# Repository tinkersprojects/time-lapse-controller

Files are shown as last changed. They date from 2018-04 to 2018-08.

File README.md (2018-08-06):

# programable Time Lapse Controller
[https://tinkersprojects.com/](https://tinkersprojects.com/)

This is a programable time lapse for a Go-Pro where tiles on the track deterands how it moves. The system can move in backward/forwards, rotate the camera and soon tilt the camera (when i get more time). It uses Lego train track as the track to guide it along and place programing tiles. The tiles are different colors which get a colour sensor reads and changes moving mode.

Currently there are 4 colours with 4 different modes. Green (also starting mode) is full travel speed with no other movements. Blue is start rotation of camera. Yellow is half the speed. Red is stop. More colours will be added soon.
The wheels are held in place with 2 x 20mmxM3 screws and driven by a 28byj-48 stepper motor. The system can be run from a 9V battery but cannot last long with out being replaced.

The PCB can be purchased from https://tinkersprojects.com/product/time-lapse-controller/

## Keep up to date
New Parts will be added, Keep up to date by following:
- Project page -> http://tinkersprojects.com/project/programable-time-lapse/
- This Thing -> https://www.thingiverse.com/thing:2825424
- my Profile -> https://www.thingiverse.com/haybailes/about

## See Other Projects
Have a look at this and other projects that I have done: http://tinkersprojects.com/

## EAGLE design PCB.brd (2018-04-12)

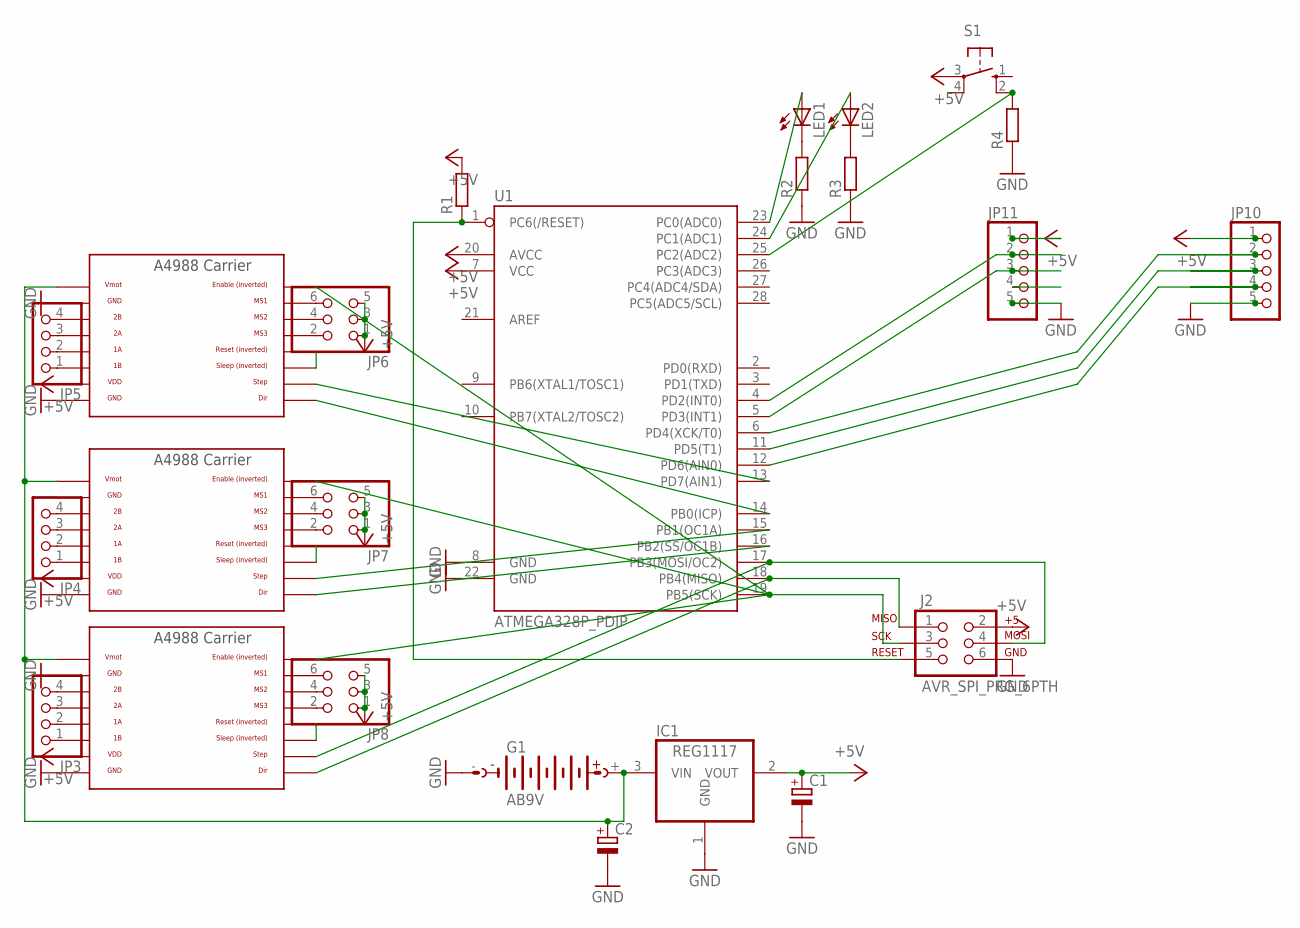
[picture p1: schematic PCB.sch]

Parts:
C1, C2: CPOL-EUE3.5-8; E3,5-8
G1: AB9V
IC1: REG1117; SOT223
J2: AVR_SPI_PRG_6PTH; 2X3
JP3, JP4, JP5: PINHD-1X4; 1X04
JP6, JP7, JP8: PINHD-2X3; 2X03
JP10, JP11: PINHD-1X5; 1X05
LED1, LED2: LED5MM
R1, R2, R3, R4: R-EU_0207/10; 0207/10
S1: 10-XX; B3F-10XX
U1: ATMEGA328P_PDIP; DIL28-3
U$1, U$2, U$4: A4988BREAKOUT

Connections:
+5V: C1.+, IC1.2 (VOUT), J2.2, JP6.1, JP6.3, JP6.5, JP7.1, JP7.3, JP7.5, JP8.1, JP8.3, JP8.5, JP10.1, JP11.1, R1.2, S1.3, U1.7 (VCC), U1.20 (AVCC), U$1.VDD, U$2.VDD, U$4.VDD
GND: C1.-, C2.-, G1.-, IC1.1 (GND), J2.6, JP10.5, JP11.5, R2.1, R3.1, R4.1, U1.8 (GND), U1.22 (GND), U$1.GND, U$1.GND@0 (GND), U$2.GND, U$2.GND@0 (GND), U$4.GND, U$4.GND@0 (GND)
unnamed: U$1.RST, U$1.SLP (SLEEP)
unnamed: U$2.RST, U$2.SLP (SLEEP)
unnamed: C2.+, G1.+, IC1.3 (VIN), U$1.VMOT, U$2.VMOT, U$4.VMOT
unnamed: J2.1, U1.18 (PB4(MISO)), U$2.DIR
unnamed: J2.3, U1.19 (PB5(SCK)), U$1.EN, U$2.EN, U$4.EN
unnamed: J2.4, U1.17 (PB3(MOSI/OC2)), U$2.STEP
unnamed: J2.5, R1.1, U1.1 (PC6(/RESET))
unnamed: JP3.1, U$2.1B
unnamed: JP3.2, U$2.1A
unnamed: JP3.3, U$2.2A
unnamed: JP3.4, U$2.2B
unnamed: JP4.1, U$1.1B
unnamed: JP4.2, U$1.1A
unnamed: JP4.3, U$1.2A
unnamed: JP4.4, U$1.2B
unnamed: JP5.1, U$4.1B
unnamed: JP5.2, U$4.1A
unnamed: JP5.3, U$4.2A
unnamed: JP5.4, U$4.2B
unnamed: JP6.2, U$4.MS3
unnamed: JP6.4, U$4.MS2
unnamed: JP6.6, U$4.MS1
unnamed: JP7.2, U$1.MS3
unnamed: JP7.4, U$1.MS2
unnamed: JP7.6, U$1.MS1
unnamed: JP8.2, U$2.MS3
unnamed: JP8.4, U$2.MS2
unnamed: JP8.6, U$2.MS1
unnamed: JP11.2, U1.4 (PD2(INT0))
unnamed: JP11.3, U1.5 (PD3(INT1))
unnamed: JP10.2, U1.6 (PD4(XCK/T0))
unnamed: JP10.3, U1.11 (PD5(T1))
unnamed: JP10.4, U1.12 (PD6(AIN0))
unnamed: U1.13 (PD7(AIN1)), U$4.STEP
unnamed: U1.14 (PB0(ICP)), U$4.DIR
unnamed: U$4.RST, U$4.SLP (SLEEP)
unnamed: U1.15 (PB1(OC1A)), U$1.STEP
unnamed: U1.16 (PB2(SS/OC1B)), U$1.DIR
unnamed: LED1.A, U1.23 (PC0(ADC0))
unnamed: LED2.A, U1.24 (PC1(ADC1))
unnamed: LED1.K (C), R2.2
unnamed: LED2.K (C), R3.2
unnamed: R4.2, S1.2 (S1), U1.25 (PC2(ADC2))

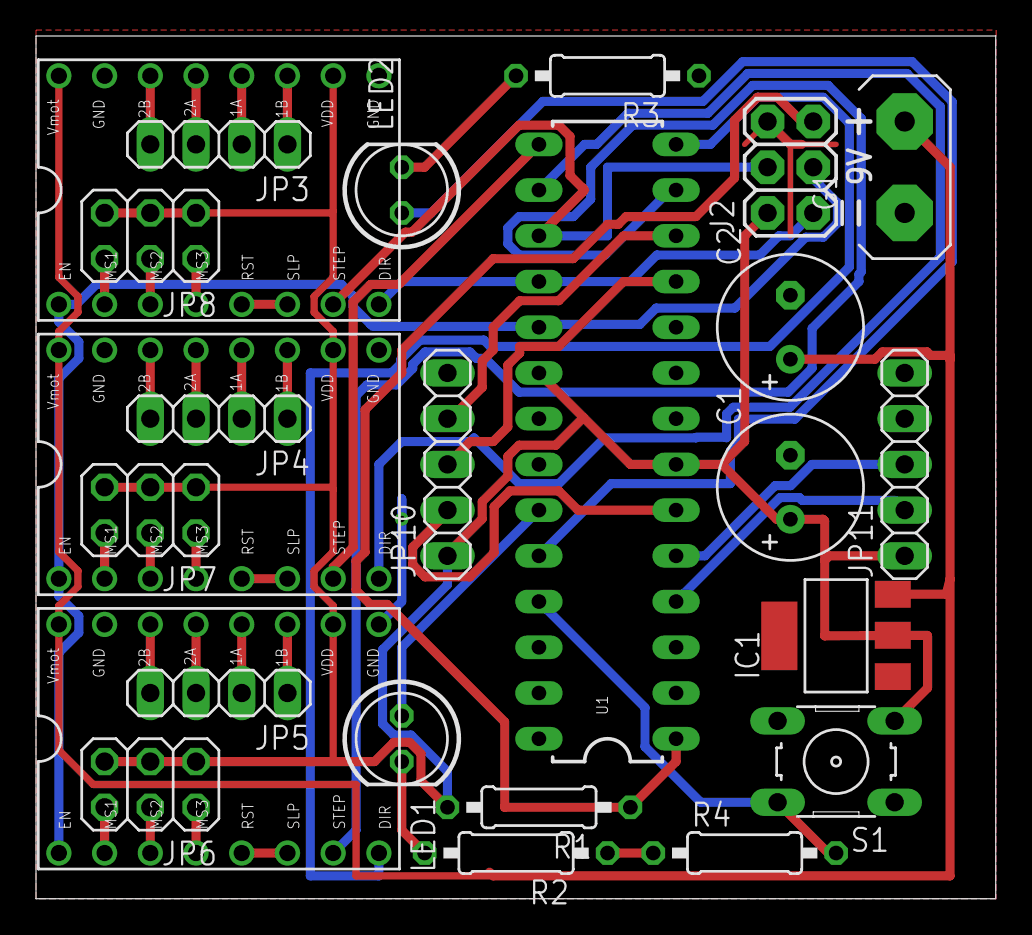
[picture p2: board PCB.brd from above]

Board: 2 copper layers, 53.3 x 47.9 mm, 24 parts (0 on the bottom side), 45 nets.

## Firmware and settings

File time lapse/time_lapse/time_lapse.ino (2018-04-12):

#include <AccelStepper.h>

#define S0 3
#define S1 2
#define S2 5
#define S3 4
#define sensorOut 6
#define enpin 13
#define buttonpin 16
#define runningLEDpin 14
#define powerLEDpin 15

#define tolrents 2

double R = 0;
double G = 0;
double B = 0;

double ProgramedArray[5][9] = {
  //R,G,B,MovDir,MovSpeed,RotDir,RotSpeed,TilDir,TilSpeed
 {43,25,31,0,200,0,0,0,0},    // green
 {34,35,30,0,200,0,200,0,0},    // White
 {23,31,44,0,100,0,100,0,0},    // Yellow
 {15,47,36,0,0,0,0,0,0}, // Red
 {50,33,15,0,100,0,100,0,0}     // Blue
};

AccelStepper rotatorstepper;
AccelStepper movingstepper;
AccelStepper tiltstepper;

void setup() 
{
  Serial.begin(115200);
  getcolor();
  pinMode(S0, OUTPUT);
  pinMode(S1, OUTPUT);
  pinMode(S2, OUTPUT);
  pinMode(S3, OUTPUT);
  pinMode(runningLEDpin, OUTPUT);
  pinMode(powerLEDpin, OUTPUT);
  pinMode(sensorOut, INPUT);
  pinMode(buttonpin, INPUT);
  pinMode(enpin, INPUT);

  digitalWrite(enpin,LOW);
  digitalWrite(S0,HIGH);
  digitalWrite(S1,LOW);
  digitalWrite(powerLEDpin,HIGH);
  digitalWrite(runningLEDpin,HIGH);
  
  rotatorstepper = AccelStepper(1,7,8);
  rotatorstepper.setMaxSpeed(200/60);
  rotatorstepper.setAcceleration(100000.0);
  rotatorstepper.move(0);
  
  movingstepper = AccelStepper(1,9,10);
  movingstepper.setMaxSpeed(200/60);
  movingstepper.setAcceleration(100000.0);
  movingstepper.move(0);
  
  tiltstepper = AccelStepper(1,11,12);
  tiltstepper.setMaxSpeed(200/60);
  tiltstepper.setAcceleration(100000.0);
  tiltstepper.move(0);
}

void loop() 
{
  getcolor();

  for(int i =0;i<sizeof(ProgramedArray);i++)
  {
    runsteps();
    if(isColor(ProgramedArray[i][0],ProgramedArray[i][1],ProgramedArray[i][2]))
    {
      movingstepper.setMaxSpeed(ProgramedArray[i][4]);
      movingstepper.setSpeed(ProgramedArray[i][4]);
      movingstepper.setPinsInverted(ProgramedArray[i][3],0,1);

      rotatorstepper.setMaxSpeed(ProgramedArray[i][6]);
      rotatorstepper.setSpeed(ProgramedArray[i][6]);
      rotatorstepper.setPinsInverted(ProgramedArray[i][5],0,1);

      tiltstepper.setMaxSpeed(ProgramedArray[i][8]);
      tiltstepper.setSpeed(ProgramedArray[i][8]);
      tiltstepper.setPinsInverted(ProgramedArray[i][7],0,1);

      runsteps();
  
      if(ProgramedArray[i][4] == 0 && ProgramedArray[i][6] == 0 && ProgramedArray[i][8] == 0)
      {
        movingstepper.stop();
        rotatorstepper.stop();
        tiltstepper.stop();
        movingstepper.disableOutputs();
        rotatorstepper.disableOutputs();
        tiltstepper.disableOutputs();
      }
      break;
    }
  }
  runsteps();
}

void runsteps()
{
  rotatorstepper.move(100);
  movingstepper.move(100);
  tiltstepper.move(100);

  rotatorstepper.run();
  movingstepper.run();
  tiltstepper.run();
}

void getcolor()
{
  R = pulseIn(sensorOut, LOW);
  G = pulseIn(sensorOut, LOW);
  B = pulseIn(sensorOut, LOW); 

  long total = R+G+B;
  R = R/total*100;
  G = G/total*100;
  B = B/total*100;
}

boolean isColor(int r,int g, int b)
{
  if(R+tolrents>r && R-tolrents<r) return false;
  if(G+tolrents>g && G-tolrents<g) return false;
  if(B+tolrents>b && B-tolrents<b) return false;
  return true;
}
  

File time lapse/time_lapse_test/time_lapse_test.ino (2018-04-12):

#include <AccelStepper.h>

#define S0 3
#define S1 2
#define S2 5
#define S3 6
#define sensorOut 4
#define enpin 13
#define buttonpin 16
#define runningLEDpin 14
#define powerLEDpin 15

#define tolrents 10

int R = 0;
int G = 0;
int B = 0;

AccelStepper rotatorstepper;
AccelStepper movingstepper;
AccelStepper tiltstepper;

void setup() 
{
  pinMode(S0, OUTPUT);
  pinMode(S1, OUTPUT);
  pinMode(S2, OUTPUT);
  pinMode(S3, OUTPUT);
  pinMode(runningLEDpin, OUTPUT);
  pinMode(powerLEDpin, OUTPUT);
  pinMode(enpin, OUTPUT);
  pinMode(sensorOut, INPUT);
  pinMode(buttonpin, INPUT);

  digitalWrite(S0,HIGH);
  digitalWrite(S1,LOW);
  digitalWrite(enpin,LOW);
  digitalWrite(powerLEDpin,HIGH);
  digitalWrite(runningLEDpin,HIGH);
  
  rotatorstepper = AccelStepper(1,7,8);
  rotatorstepper.setMaxSpeed(100);
  rotatorstepper.setAcceleration(100.0);
  rotatorstepper.move(1000);
  
  movingstepper = AccelStepper(1,9,10);
  movingstepper.setMaxSpeed(100);
  movingstepper.setAcceleration(100.0);
  movingstepper.move(1000);
  
  tiltstepper = AccelStepper(1,11,12);
  tiltstepper.setMaxSpeed(100);
  tiltstepper.setAcceleration(100.0);
  tiltstepper.move(1000);
}

void loop() 
{
  
  rotatorstepper.move(1000);
  movingstepper.move(1000);
  tiltstepper.move(1000);
  rotatorstepper.run();
  movingstepper.run();
  tiltstepper.run();
}

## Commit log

2018-04-12 Add files via upload
    files upload
    [PCB.brd, PCB.sch]
2018-04-12 Add files via upload
    Arduino files upload

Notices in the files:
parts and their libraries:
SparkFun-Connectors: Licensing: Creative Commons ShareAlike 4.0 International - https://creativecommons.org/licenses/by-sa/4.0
